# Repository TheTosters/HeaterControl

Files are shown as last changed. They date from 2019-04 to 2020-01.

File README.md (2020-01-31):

# IMPORTANT
Toolchain:
 * gcc-arm-none-eabi-8-2018-q4-major, or
 * gcc-arm-none-eabi-8-2019-q3-update-linux

NRF SDK:
 * nRF5_SDK_15.2.0_9412b96

You also need nrfprog tools and small patch for SDK from CMSIS. But this is handled by ```preapre_env.sh```

# To build & run tests...

This is super-glue solution, so your eyes will bleeed...
It will use host compiler (not cross-compiler) to build host based tests.
It is NOT ment to test all, only most complicated logic. So to have test build and run you have to:
```
cmake .. -DBUILD_TESTS=ON
make all
```

then you can call for example:
```./test/time_schedule_tests```

# Manual patching SDK
If you set C++ to use C++17 dialect then compilation fails :P You have to manualy patch NordicSDK (15.2) and upgrade CMSIS to have things working go here
[Arm CMSIS 5 on Github](https://github.com/ARM-software/CMSIS_5) and download following files which should be placed here:

| CMSIS file |  | Destination |
|------------| - |-------|
|libarm_cortexM4lf_math.a, libarm_cortexM4l_math.a  | > | nordic_SDK_15.2/components/toolchain/cmsis/dsp/GCC|
|arm_cortexM4lf_math.lib  arm_cortexM4l_math.lib | > | nordic_SDK_15.2/components/toolchain/cmsis/dsp/ARM
|CMSIS_5-develop/CMSIS/Core/Include | > |  nordic_SDK_15.2/components/toolchain/cmsis/include |

```clean & build```  all should work

# Variants
This repository contains several firmware variants. It can be used by setting proper defines for ```CMake```, most easy way to do it is to execute ```ccmake```. Below is list of build variants and their descriptions:

| Variant | Entry point | Description |
|-|-|-|
|Indoor SHT_ADV | main_indoor_1.cpp | BT: Advertisement <br> Sensor: SHT30 <br> Buttons: None <br> LED: None <br> Display: None |
|Indoor SHT_GATT | main_indoor_1a.cpp | BT: GATT <br> Sensor: SHT30 <br> Buttons: None <br> LED: None <br> Display: None |
|Indoor DS_FULL | main_indoor_1.cpp | BT: Advertisement <br> Sensor: DS18B20 <br> Buttons: yes <br> LED: None <br> Display: Yes |

# Origins
first instruction taken from:
https://github.com/Polidea/cmake-nRF5x
It is constantly changed and improved (or downproved :P)

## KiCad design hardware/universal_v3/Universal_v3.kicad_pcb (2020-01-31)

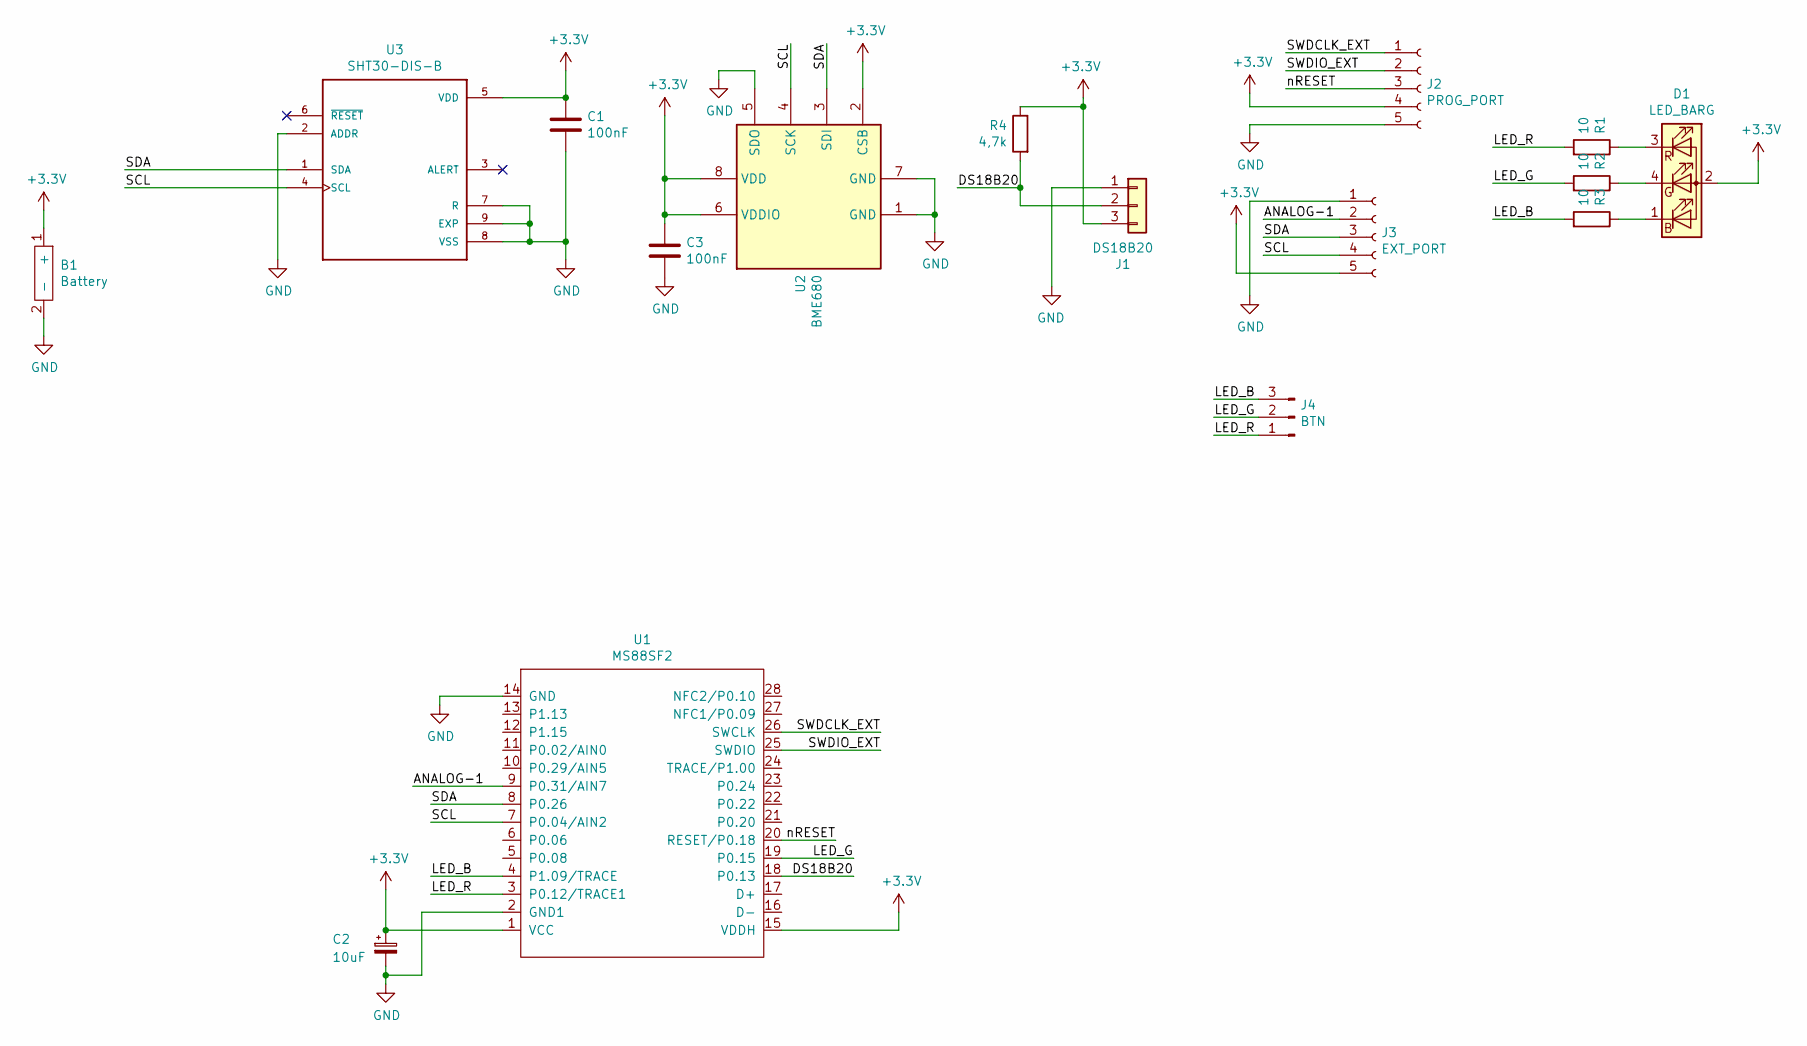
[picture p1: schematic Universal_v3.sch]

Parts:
B1: Battery; Cr2032-Holder
C1, C3: 100nF; C_0402_1005Metric
C2: 10uF; CP_EIA-2012-12_Kemet-R
D1: LED_BARG; Everlight_19-237_R6GHBHC-M07_2T
J1: DS18B20; 3Pads
J2: PROG_PORT; 5xPad
J3: EXT_PORT; 5xPad
J4: BTN; PinHeader_1x03_P2.54mm_Vertical
R1, R2, R3: 10; R_0402_1005Metric
R4: 4,7k; R_0402_1005Metric
U1: MS88SF2
U2: BME680; Bosch_LGA-8_3x3mm_P0.8mm_ClockwisePinNumbering
U3: SHT30-DIS-B; DFN250X250X100-9N

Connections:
+3V3: B1.1 (+), C1.1, C2.1, C3.1, D1.2 (A), J1.3, J2.4, J3.5, R4.1, U1.1 (VCC), U1.15 (VDDH), U2.2 (CSB), U2.6 (VDDIO), U2.8 (VDD), U3.5 (VDD)
/ANALOG-1: J3.2, U1.9 (P0.31/AIN7)
/DS18B20: J1.2, R4.2, U1.18 (P0.13)
/LED_B: J4.3, R3.2, U1.4 (P1.09/TRACE)
/LED_G: J4.2, R2.2, U1.19 (P0.15)
/LED_R: J4.1, R1.2, U1.3 (P0.12/TRACE1)
/SCL: J3.4, U1.7 (P0.04/AIN2), U2.4 (SCK), U3.4 (SCL)
/SDA: J3.3, U1.8 (P0.26), U2.3 (SDI), U3.1 (SDA)
/SWDCLK_EXT: J2.1, U1.26 (SWCLK)
/SWDIO_EXT: J2.2, U1.25 (SWDIO)
/nRESET: J2.3, U1.20 (RESET/P0.18)
GND: B1.2 (-), C1.2, C2.2, C3.2, J1.1, J2.5, J3.1, U1.2 (GND1), U1.14 (GND), U2.1 (GND), U2.5 (SDO), U2.7 (GND), U3.2 (ADDR), U3.7 (R), U3.8 (VSS), U3.9 (EXP)
unnamed: D1.1 (BK), R3.1
unnamed: D1.3 (RK), R1.1
unnamed: D1.4 (GK), R2.1

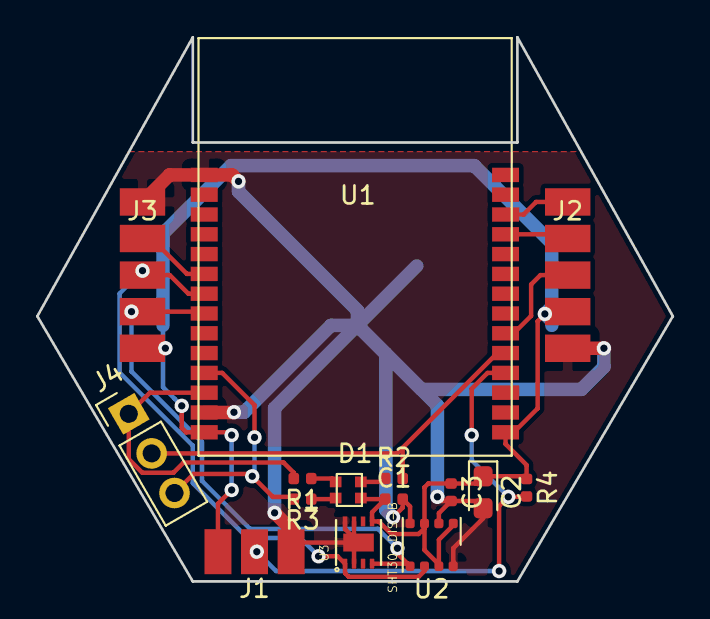
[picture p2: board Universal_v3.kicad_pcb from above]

Board: 2 copper layers, 35.3 x 30.2 mm, 16 parts (1 on the bottom side), 15 nets.

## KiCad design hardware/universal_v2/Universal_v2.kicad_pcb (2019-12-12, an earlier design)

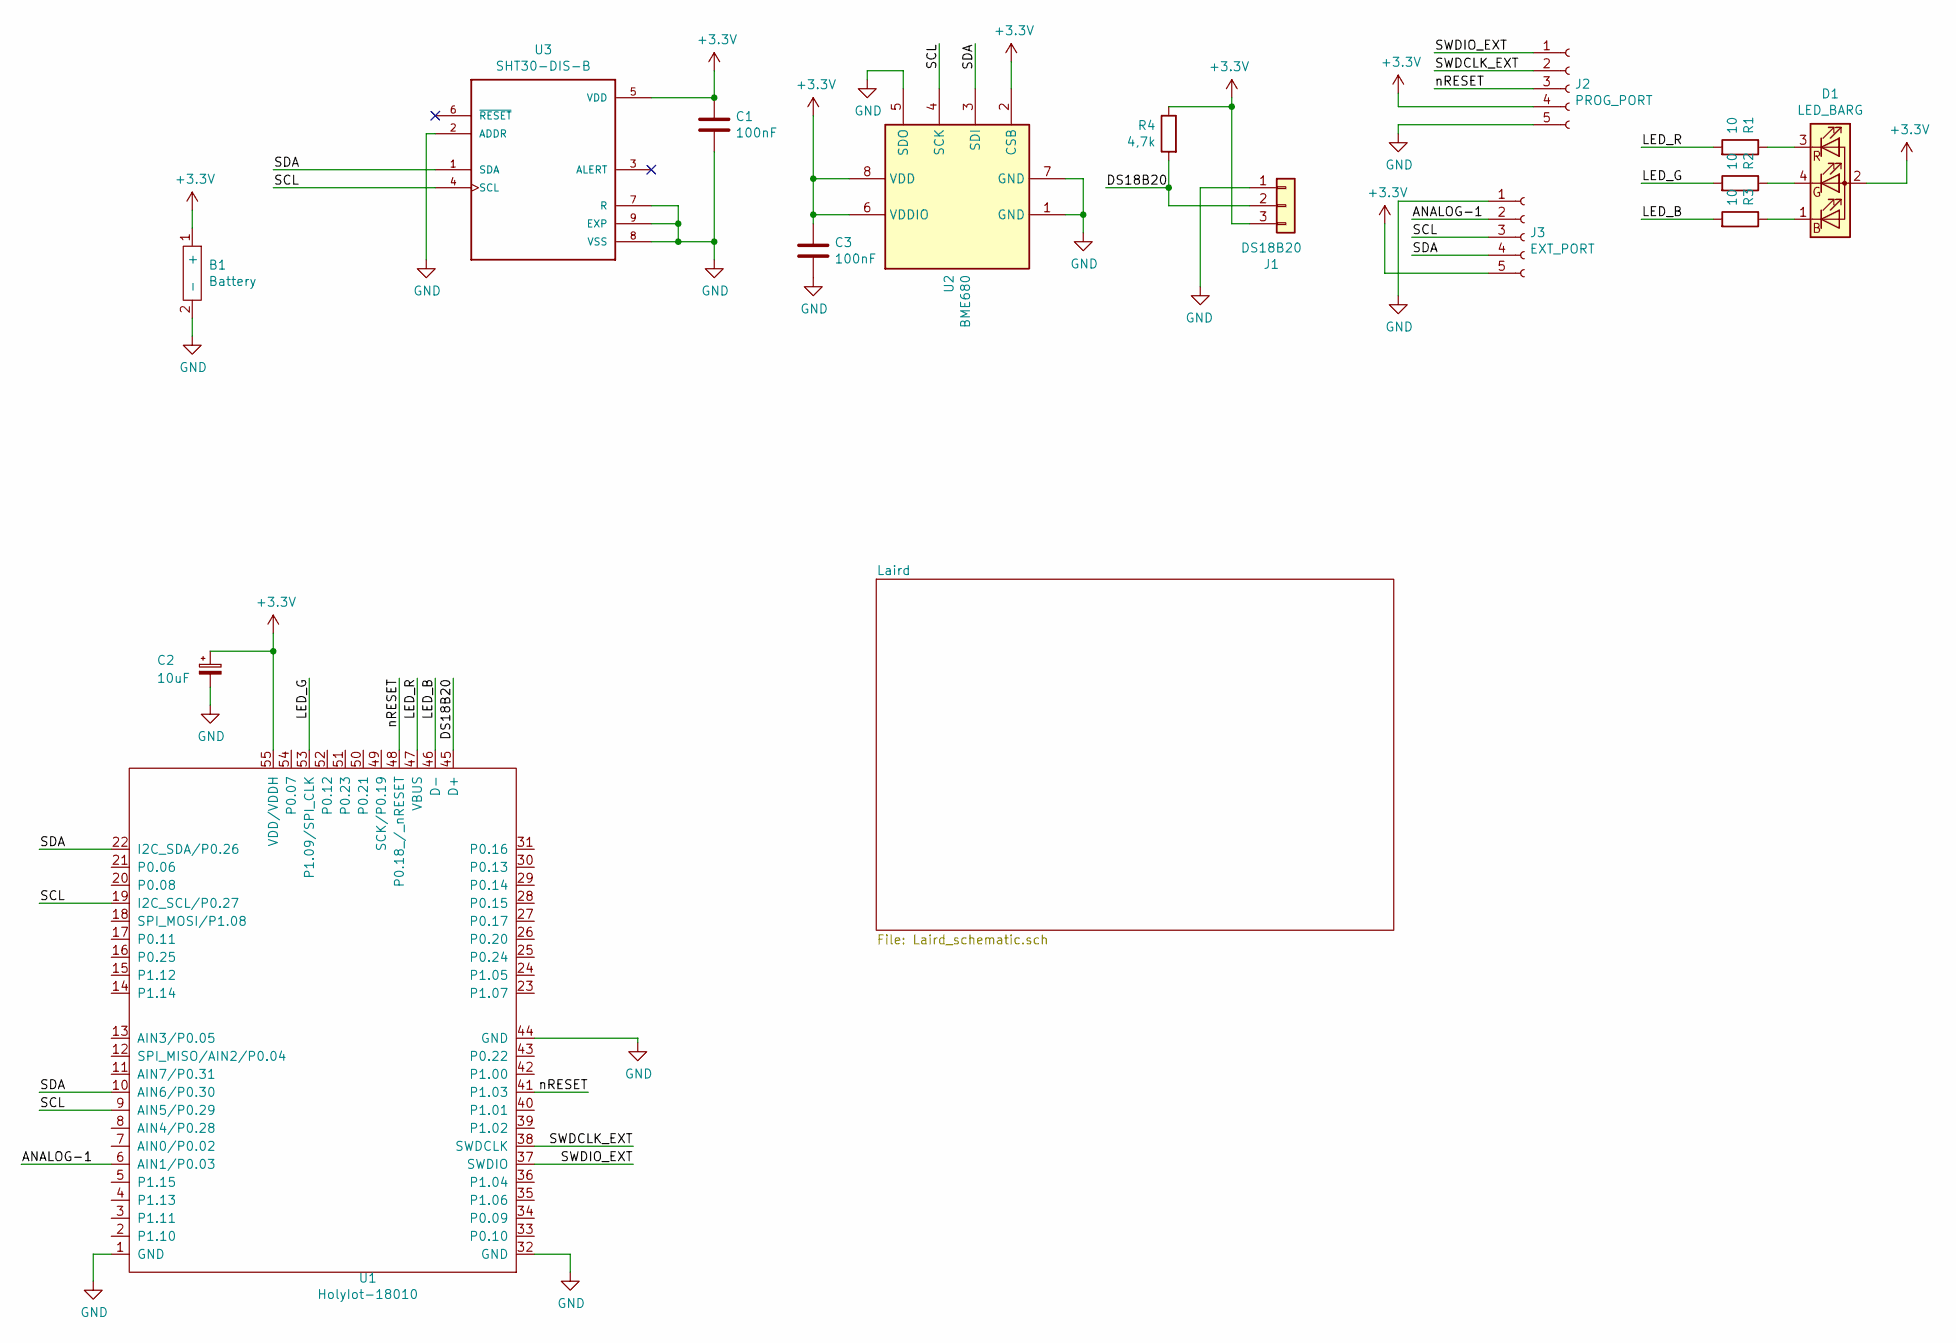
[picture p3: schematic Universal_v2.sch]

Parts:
B1: Battery; Cr2032-Holder
C1, C3: 100nF; C_0402_1005Metric
C2: 10uF; CP_EIA-2012-12_Kemet-R
D1: LED_BARG; Everlight_19-237_R6GHBHC-M07_2T
J1: DS18B20; 3Pads
J2: PROG_PORT; 5xPad
J3: EXT_PORT; 5xPad
R1, R2, R3: 10; R_0402_1005Metric
R4: 4,7k; R_0402_1005Metric
U1: HolyIot-18010; HolyIot_18010
U2: BME680; Bosch_LGA-8_3x3mm_P0.8mm_ClockwisePinNumbering
U3: SHT30-DIS-B; DFN250X250X100-9N

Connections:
+3V3: B1.1 (+), C1.1, C2.1, C3.1, D1.2 (A), J1.3, J2.4, J3.5, R4.1, U1.55 (VDD/VDDH), U2.2 (CSB), U2.6 (VDDIO), U2.8 (VDD), U3.5 (VDD); also elsewhere on the board
/ANALOG-1: J3.2, U1.6 (AIN1/P0.03)
/DS18B20: J1.2, R4.2, U1.45 (D+)
/LED_B: R3.2, U1.46 (D-)
/LED_G: R2.2, U1.53 (P1.09/SPI_CLK)
/LED_R: R1.2, U1.47 (VBUS)
/SCL: J3.3, U1.9 (AIN5/P0.29), U1.19 (I2C_SCL/P0.27), U2.4 (SCK), U3.4 (SCL)
/SDA: J3.4, U1.10 (AIN6/P0.30), U1.22 (I2C_SDA/P0.26), U2.3 (SDI), U3.1 (SDA)
/SWDCLK_EXT: J2.2, U1.38 (SWDCLK)
/SWDIO_EXT: J2.1, U1.37 (SWDIO)
/nRESET: J2.3, U1.41 (P1.03), U1.48 (P0.18_/_nRESET)
GND: B1.2 (-), C1.2, C2.2, C3.2, J1.1, J2.5, J3.1, U1.1 (GND), U1.32 (GND), U1.44 (GND), U2.1 (GND), U2.5 (SDO), U2.7 (GND), U3.2 (ADDR), U3.7 (R), U3.8 (VSS), U3.9 (EXP); also elsewhere on the board
unnamed: D1.1 (BK), R3.1
unnamed: D1.3 (RK), R1.1
unnamed: D1.4 (GK), R2.1

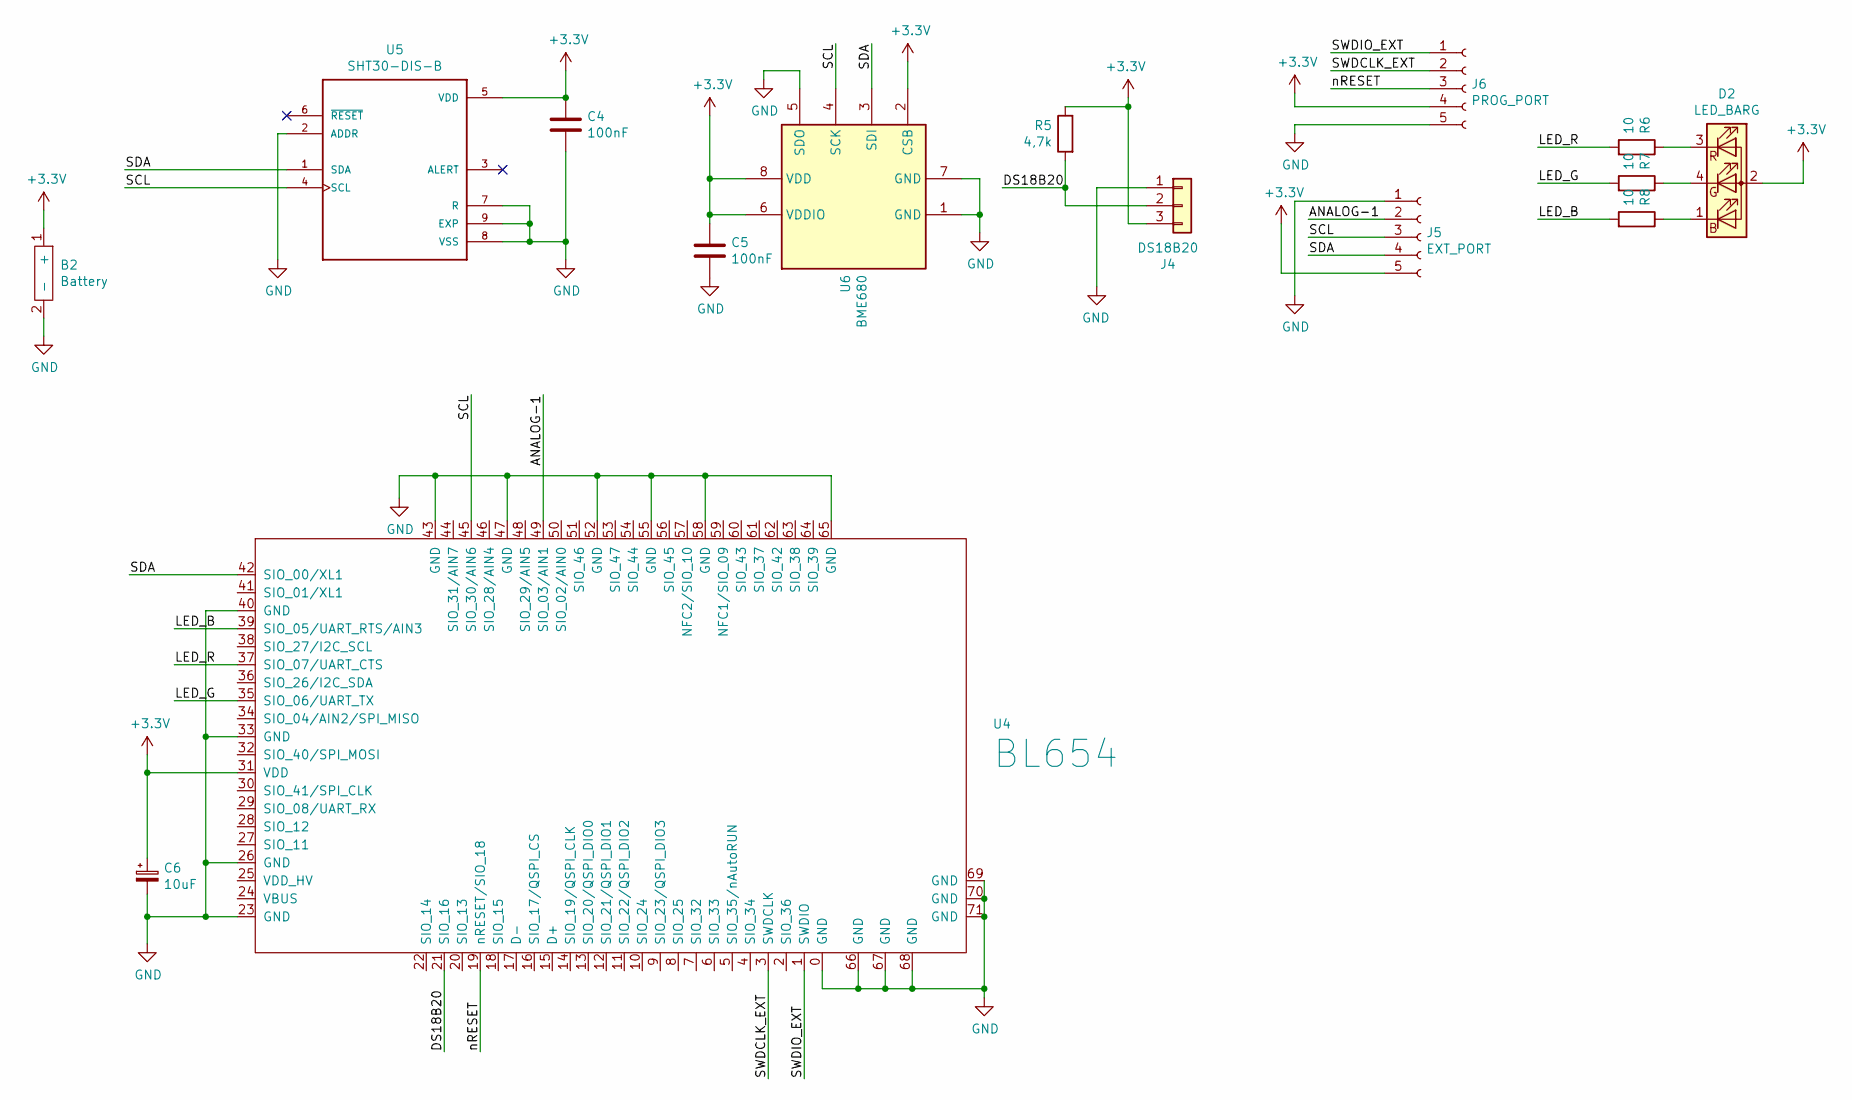
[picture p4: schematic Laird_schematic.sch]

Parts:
B2: Battery; Cr2032-Holder
C4, C5: 100nF; C_0402_1005Metric
C6: 10uF; CP_EIA-2012-12_Kemet-R
D2: LED_BARG; Everlight_19-237_R6GHBHC-M07_2T
J4: DS18B20; 3Pads
J5: EXT_PORT; 5xPad
J6: PROG_PORT; 5xPad
R5: 4,7k; R_0402_1005Metric
R6, R7, R8: 10; R_0402_1005Metric
U4: BL654
U5: SHT30-DIS-B; DFN250X250X100-9N
U6: BME680; Bosch_LGA-8_3x3mm_P0.8mm_ClockwisePinNumbering

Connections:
+3V3: B2.1 (+), C4.1, C5.1, C6.1, D2.2 (A), J4.3, J5.5, J6.4, R5.1, U4.31 (VDD), U5.5 (VDD), U6.2 (CSB), U6.6 (VDDIO), U6.8 (VDD); also elsewhere on the board
/Laird/ANALOG-1: J5.2, U4.49 (SIO_03/AIN1)
/Laird/DS18B20: J4.2, R5.2, U4.21 (SIO_16)
/Laird/LED_B: R8.2, U4.39 (SIO_05/UART_RTS/AIN3)
/Laird/LED_G: R7.2, U4.35 (SIO_06/UART_TX)
/Laird/LED_R: R6.2, U4.37 (SIO_07/UART_CTS)
/Laird/SCL: J5.3, U4.45 (SIO_30/AIN6), U5.4 (SCL), U6.4 (SCK)
/Laird/SDA: J5.4, U4.42 (SIO_00/XL1), U5.1 (SDA), U6.3 (SDI)
/Laird/SWDCLK_EXT: J6.2, U4.3 (SWDCLK)
/Laird/SWDIO_EXT: J6.1, U4.1 (SWDIO)
/Laird/nRESET: J6.3, U4.19 (nRESET/SIO_18)
GND: B2.2 (-), C4.2, C5.2, C6.2, J4.1, J5.1, J6.5, U4.0 (GND), U4.23 (GND), U4.26 (GND), U4.33 (GND), U4.40 (GND), U4.43 (GND), U4.47 (GND), U4.52 (GND), U4.55 (GND), U4.58 (GND), U4.65 (GND), U4.66 (GND), U4.67 (GND), U4.68 (GND), U4.69 (GND), U4.70 (GND), U4.71 (GND), U5.2 (ADDR), U5.7 (R), U5.8 (VSS), U5.9 (EXP), U6.1 (GND), U6.5 (SDO), U6.7 (GND); also elsewhere on the board
unnamed: D2.1 (BK), R8.1
unnamed: D2.3 (RK), R6.1
unnamed: D2.4 (GK), R7.1

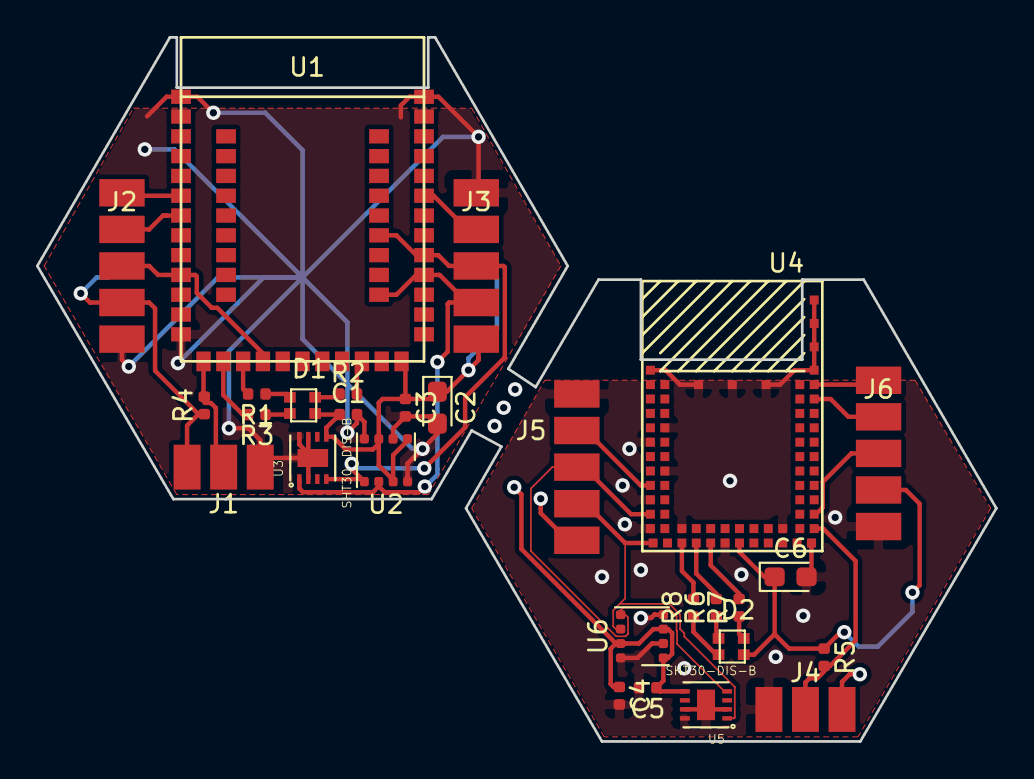
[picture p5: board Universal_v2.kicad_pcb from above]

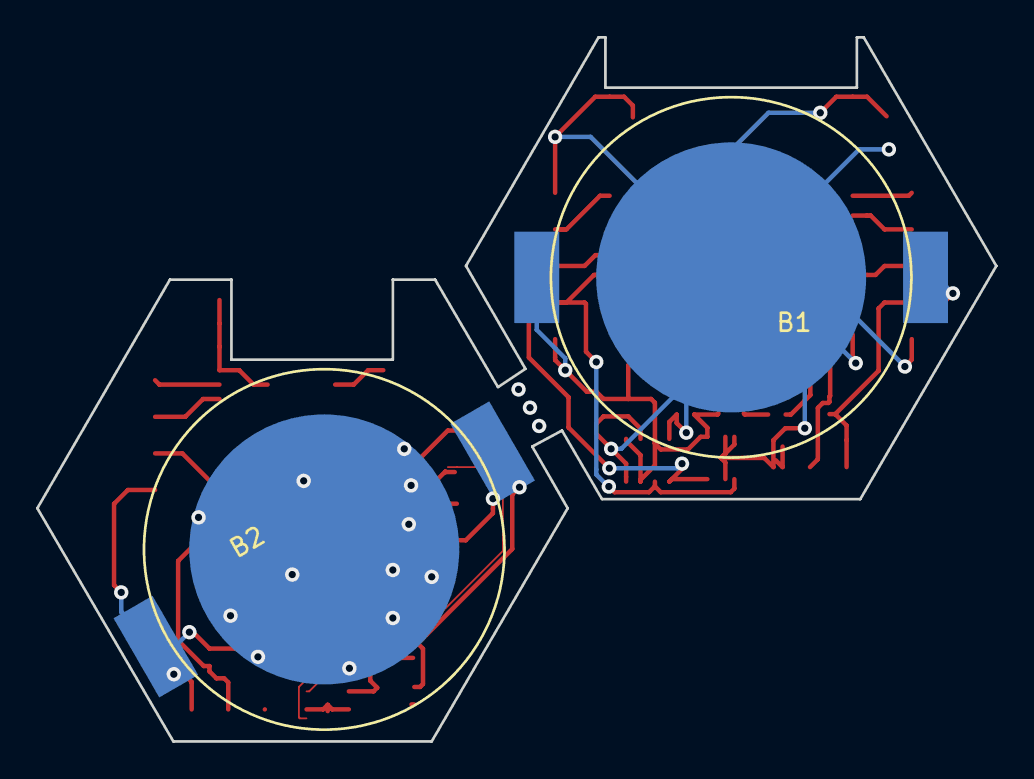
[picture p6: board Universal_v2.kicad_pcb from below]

Board: 2 copper layers, 53.3 x 39.1 mm, 30 parts (2 on the bottom side), 28 nets.

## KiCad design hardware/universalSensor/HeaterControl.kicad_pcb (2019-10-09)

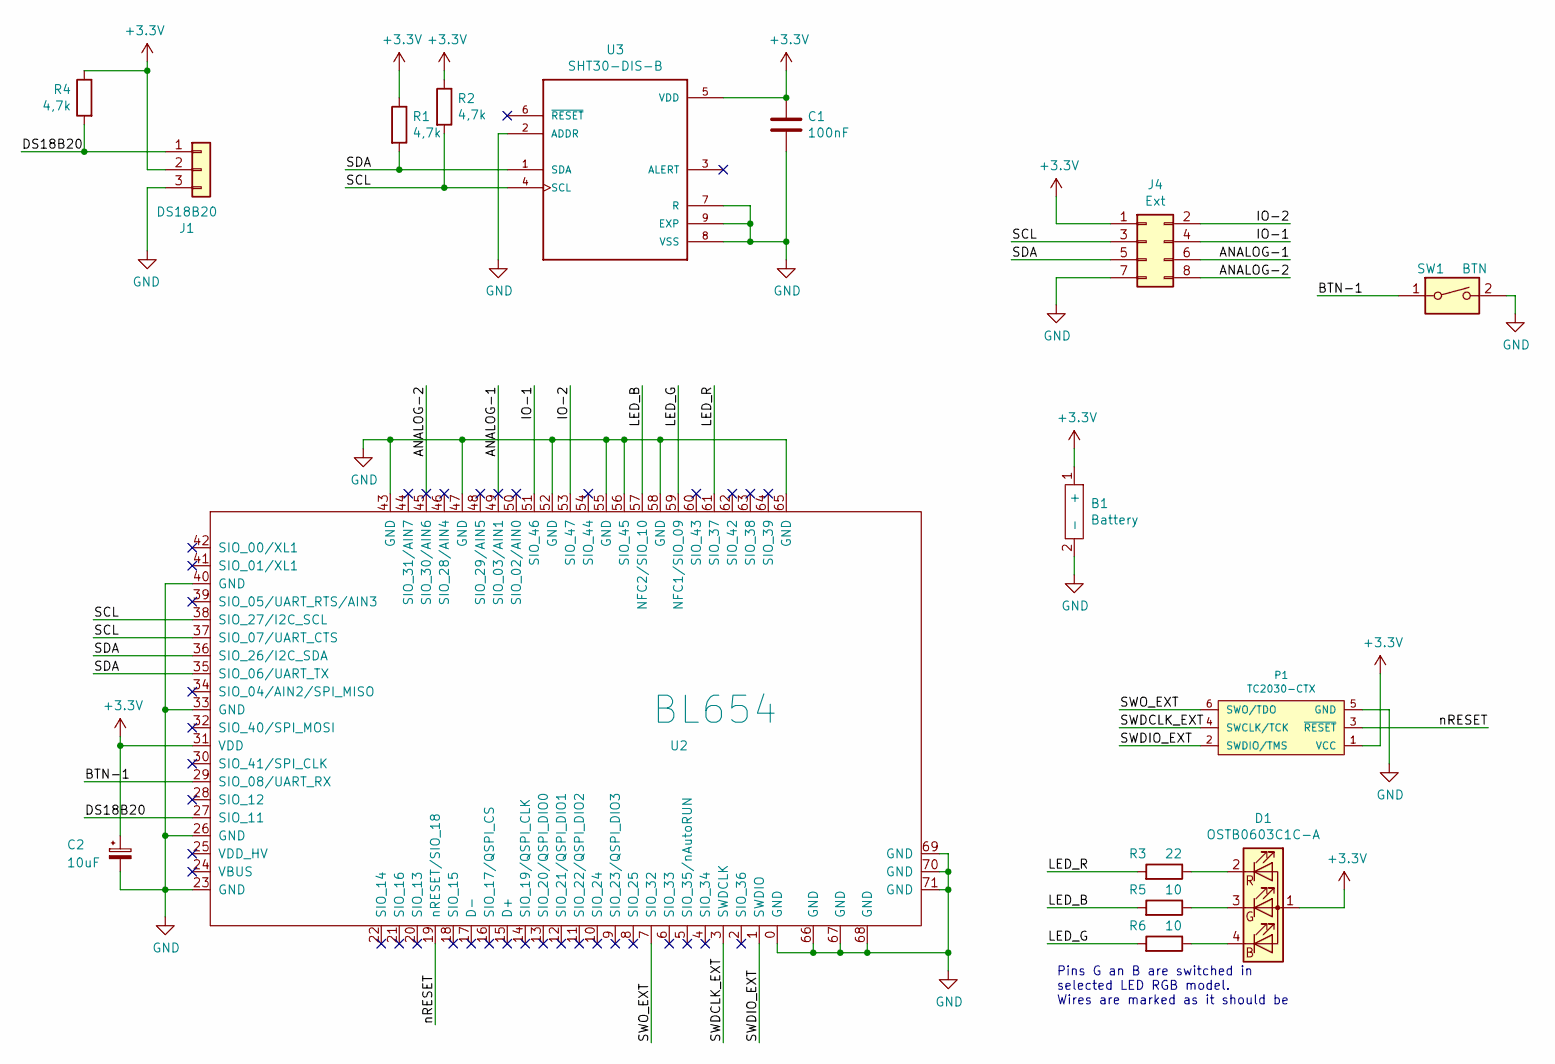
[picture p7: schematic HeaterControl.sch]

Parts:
B1: Battery; Cr2032-Holder
C1: 100nF; C_0402_1005Metric
C2: 10uF; CP_EIA-2012-12_Kemet-R
D1: OSTB0603C1C-A; LED_PACKAGE_1.6x1.5mm
J1: DS18B20; PinHeader_1x03_P2.54mm_Vertical_SMD_Pin1Left
J4: Ext; PinHeader_2x04_P1.00mm_Vertical_SMD
P1: TC2030-CTX; TC2030-NL_SMALL
R1, R2, R4: 4,7k; R_0402_1005Metric
R3: 22; R_0402_1005Metric
R5, R6: 10; R_0402_1005Metric
SW1: BTN; R_1206_3216Metric
U2: BL654
U3: SHT30-DIS-B; DFN250X250X100-9N

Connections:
+3V3: B1.1 (+), C1.1, C2.1, D1.1 (A), J1.2, J4.1, P1.1 (VCC), R1.1, R2.1, R4.1, U2.31 (VDD), U3.5 (VDD); also elsewhere on the board
/ANALOG-1: J4.6, U2.49 (SIO_03/AIN1)
/ANALOG-2: J4.8, U2.45 (SIO_30/AIN6)
/BTN-1: SW1.1, U2.29 (SIO_08/UART_RX)
/DS18B20: J1.1, R4.2, U2.27 (SIO_11)
/IO-1: J4.4, U2.51 (SIO_46)
/IO-2: J4.2, U2.53 (SIO_47)
/LED_B: R5.2, U2.57 (NFC2/SIO_10)
/LED_G: R6.2, U2.59 (NFC1/SIO_09)
/LED_R: R3.2, U2.61 (SIO_37)
/SCL: J4.3, R2.2, U2.37 (SIO_07/UART_CTS), U2.38 (SIO_27/I2C_SCL), U3.4 (SCL)
/SDA: J4.5, R1.2, U2.35 (SIO_06/UART_TX), U2.36 (SIO_26/I2C_SDA), U3.1 (SDA)
/SWDCLK_EXT: P1.4 (SWCLK/TCK), U2.3 (SWDCLK); also elsewhere on the board
/SWDIO_EXT: P1.2 (SWDIO/TMS), U2.1 (SWDIO); also elsewhere on the board
/SWO_EXT: P1.6 (SWO/TDO), U2.7 (SIO_32); also elsewhere on the board
/nRESET: P1.3 (~RESET~), U2.19 (nRESET/SIO_18); also elsewhere on the board
GND: B1.2 (-), C1.2, C2.2, J1.3, J4.7, P1.5 (GND), SW1.2, U2.0 (GND), U2.23 (GND), U2.26 (GND), U2.33 (GND), U2.40 (GND), U2.43 (GND), U2.47 (GND), U2.52 (GND), U2.55 (GND), U2.56 (SIO_45), U2.58 (GND), U2.65 (GND), U2.66 (GND), U2.67 (GND), U2.68 (GND), U2.69 (GND), U2.70 (GND), U2.71 (GND), U3.2 (ADDR), U3.7 (R), U3.8 (VSS), U3.9 (EXP); also elsewhere on the board
unnamed: D1.2 (RK), R3.1
unnamed: D1.3 (GK), R5.1
unnamed: D1.4 (BK), R6.1

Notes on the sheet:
Pins G an B are switched in selected LED RGB model. Wires are marked as it should be

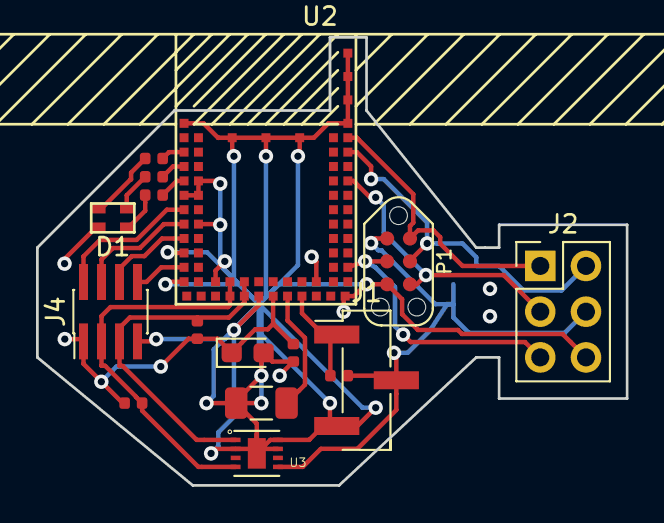
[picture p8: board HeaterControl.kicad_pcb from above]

Board: 2 copper layers, 32.8 x 24.9 mm, 17 parts (1 on the bottom side), 20 nets.

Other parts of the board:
J2: DEV_PORT; PinHeader_2x03_P2.54mm_Vertical

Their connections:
+3V3: J2.4; also elsewhere on the board
/SWDCLK_EXT: J2.2; also elsewhere on the board
/SWDIO_EXT: J2.1; also elsewhere on the board
/SWO_EXT: J2.3; also elsewhere on the board
/nRESET: J2.5; also elsewhere on the board
GND: J2.6; also elsewhere on the board

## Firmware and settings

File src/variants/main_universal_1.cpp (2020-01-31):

extern "C" {
#include <components/libraries/delay/nrf_delay.h>
#include <components/boards/boards.h>
#include <components/libraries/log/nrf_log_ctrl.h>
#include <components/libraries/log/nrf_log.h>
#include <components/libraries/log/nrf_log_default_backends.h>
#include <components/libraries/util/app_error.h>
#include <components/softdevice/common/nrf_sdh.h>
#include <components/softdevice/common/nrf_sdh_ble.h>
#include <components/libraries/pwr_mgmt/nrf_pwr_mgmt.h>
#include <components/libraries/bsp/bsp.h>
#include <components/libraries/timer/app_timer.h>
#include <components/ble/ble_services/ble_dfu/ble_dfu.h>
#include <integration/nrfx/legacy/nrf_drv_clock.h>
#include <config/nrf52840/config/sdk_config.h>
}

#include "bridges/i2c_bridge.h"
#include "buttons.h"
#include "display.h"
#include "sensors/sensor_factory.h"
//#include "bluetooth/btle_transmiter.h"
#include "calendar.h"
#include "resources/xbm_icons.h"
#include "screens/default_screen.h"
#include "screens/status_screen.h"
#include "screens/time_setup_screen.h"
#include "screens/screens_stack.h"
#include "observable.h"
#include "events_dispatcher.h"
#include "schedule/temperatureScheduler.h"
#include "schedule/weekScheduleBuilder.h"
#include "heating_model.h"
#include "types/hardware_pin.h"
#include "leds/led_factory.h"
#include "leds/led_color.h"
//#include "bluetooth/gatt_stack.h"
//#include "bluetooth/services/gatt_service.h"
#include "communication.h"
#include <stdint.h>

#define APP_BLE_OBSERVER_PRIO           3
#define APP_BLE_CONN_CFG_TAG            1

extern void setupScreens();

void powerManagementInit() {
  ret_code_t err_code;
  err_code = nrf_pwr_mgmt_init();
  APP_ERROR_CHECK(err_code);
}

void initLowFreqClock() {
  ret_code_t err_code = nrf_drv_clock_init();
  APP_ERROR_CHECK(err_code);
  nrf_drv_clock_lfclk_request(NULL);
}

uint32_t millis(void)
{
  return(app_timer_cnt_get() / 32.768);
}
#define OVERFLOW_1 ((uint32_t)(0xFFFFFFFF/32.768))

uint32_t compareMillis(uint32_t previousMillis, uint32_t currentMillis)
{
  if(currentMillis < previousMillis) {
    return currentMillis + OVERFLOW_1 + 1 - previousMillis;
  } else {
    return currentMillis - previousMillis;
  }
}

void setupMeasureOnButton() {
#if defined(MEASURE_ON_BUTTON_PRESS) && MEASURE_ON_BUTTON_PRESS == 1
  buttons().addObserver([](ButtonId event) {
    RGBLeds().setColor(LedColor::GREEN, 1 * 1000);
    Communication::sendMeasurementsNow();
  });
  NRF_LOG_INFO("ENABLE: Measure on Button press");
#else
  NRF_LOG_INFO("DISABLE: Measure on Button press");
#endif
}

void pinsFix() {
  //in this hardware following pins are bridged and need to be set as a high impedance
  //P0.27 & P0.7
  //P0.26 & P0.6
  nrf_gpio_cfg_input(NRF_GPIO_PIN_MAP(0, 6), NRF_GPIO_PIN_NOPULL);
  nrf_gpio_cfg_input(NRF_GPIO_PIN_MAP(0, 7), NRF_GPIO_PIN_NOPULL);
  NRF_LOG_INFO("ENABLE: Pins P0.06 & P0.07 as high impedance");
}

int main( int argc, const char* argv[] ) {
  NRF_LOG_INIT(NULL);
  NRF_LOG_DEFAULT_BACKENDS_INIT();
  NRF_LOG_INFO("Start");
  NRF_LOG_FLUSH();

  bsp_board_init(BSP_INIT_LEDS | BSP_INIT_BUTTONS);
  pinsFix();
  powerManagementInit();
  initLowFreqClock();

  ret_code_t err = app_timer_init();
  APP_ERROR_CHECK(err);

  RGBLeds().setColor(LedColor::NONE, 3*1000);

  //All data types which are used by classes which uses dispatching into main
  //thread should be placed here!
  EventsDispatcher<10,
    ButtonId, app_timer_event_t, BtleTransmiter*, BleEventPtr> dispatcher;

  Communication::build();
  Communication::start();
  NRF_LOG_FLUSH();

  setupScreens();
  setupMeasureOnButton();

#ifdef DEBUG_BUILD
  sensors().addObserver([](TemperatureC t, RelativeHumidity h, BatteryPrc  b){
    NRF_LOG_WARNING("Temp: %s; Hum: %s, Batt: %s\n",
        t.toString().c_str(), h.toString().c_str(), b.toString().c_str() );
  });
  NRF_LOG_INFO("ENABLE: Debug sensors dump");
#endif

  NRF_LOG_INFO("Config done, entering main loop");
  NRF_LOG_FLUSH();

  RGBLeds().setColor(LedColor::GREEN, 3 * 1000);
  while (true) {
    dispatcher.process();
    nrf_pwr_mgmt_run();
  }
  return 0;
}

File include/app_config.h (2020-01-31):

//This are defines for sdk

//Bluetooth magic
#define PEER_MANAGER_ENABLED 1
#define NRF_BLE_QWR_ENABLED 1
#define FDS_ENABLED 1
#define NRF_BLE_GATT_ENABLED 1
#define BLE_ADVERTISING_ENABLED 1
#define NRF_BLE_CONN_PARAMS_ENABLED 1
#define NRF_SDH_BLE_PERIPHERAL_LINK_COUNT 1
#define NRF_BLE_CONN_PARAMS_MAX_SLAVE_LATENCY_DEVIATION 499
#define NRF_BLE_CONN_PARAMS_MAX_SUPERVISION_TIMEOUT_DEVIATION 65535
#define NRF_FSTORAGE_ENABLED 1
#define NRF_FSTORAGE_PARAM_CHECK_DISABLED 0
//+1 because of DFU
#define NRF_SDH_BLE_VS_UUID_COUNT (5+0)
#define NRF_SDH_BLE_LOG_LEVEL 4
#define NRF_SDH_LOG_LEVEL 4
#define NRF_SDH_SOC_LOG_LEVEL 4

/* Needed in production board, wasn't needed in dev board*/
#define NRF_SDH_CLOCK_LF_RC_CTIV 16
#define NRF_SDH_CLOCK_LF_RC_TEMP_CTIV 2
#define NRF_SDH_CLOCK_LF_ACCURACY NRF_CLOCK_LF_ACCURACY_500_PPM
#define NRF_SDH_CLOCK_LF_SRC 0
/* ^------- */

//SAADC
#define SAADC_ENABLED 1
#define SAADC_CONFIG_RESOLUTION 1
#define SAADC_CONFIG_OVERSAMPLE 0
#define SAADC_CONFIG_LP_MODE 0
#define SAADC_CONFIG_IRQ_PRIORITY 6

#define NRFX_SAADC_ENABLED 1
#define NRFX_SAADC_CONFIG_RESOLUTION 1
#define NRFX_SAADC_CONFIG_OVERSAMPLE 0
#define NRFX_SAADC_CONFIG_LP_MODE 0
#define NRFX_SAADC_CONFIG_IRQ_PRIORITY 6

#define GPIO_COUNT 2
//BSP support
#define BUTTON_ENABLED 1
#define APP_GPIOTE_ENABLED 1
#define NRFX_GPIOTE_ENABLED 1
#define GPIOTE_ENABLED 1
#define GPIOTE_CONFIG_NUM_OF_LOW_POWER_EVENTS 4

#define APP_FIFO_ENABLED 1
#define APP_SCHEDULER_ENABLED 1

//Timer support
#define APP_TIMER_ENABLED 1
#define APP_TIMER_CONFIG_USE_SCHEDULER 1  //we want timer to use app scheduler
#define NRF_CLOCK_ENABLED 1
#define CLOCK_CONFIG_LF_SRC 1

//Logs
#ifdef DEBUG_BUILD
#define NRF_LOG_ENABLED 1
#define NRF_LOG_USES_TIMESTAMP 0
#define NRF_LOG_BACKEND_UART_ENABLED 0
#define NRF_LOG_BACKEND_RTT_ENABLED 1
#define NRF_LOG_DEFERRED 0
#define NRF_LOG_DEFAULT_LEVEL 4
#else
#define NRF_LOG_ENABLED 0
#define NRF_LOG_USES_TIMESTAMP 0
#define NRF_LOG_BACKEND_UART_ENABLED 0
#define NRF_LOG_BACKEND_RTT_ENABLED 0
#define NRF_LOG_DEFERRED 0
#define NRF_LOG_DEFAULT_LEVEL 4
#endif

//SEGGER RTT
#define NRF_LOG_BACKEND_RTT_TEMP_BUFFER_SIZE 64
#define NRF_LOG_BACKEND_RTT_TX_RETRY_CNT 5
#define NRF_LOG_BACKEND_RTT_TX_RETRY_DELAY_MS 2

#define SEGGER_RTT_CONFIG_BUFFER_SIZE_UP 512
#define SEGGER_RTT_CONFIG_MAX_NUM_UP_BUFFERS 2
#define SEGGER_RTT_CONFIG_BUFFER_SIZE_DOWN 16
#define SEGGER_RTT_CONFIG_MAX_NUM_DOWN_BUFFERS 2
#define SEGGER_RTT_CONFIG_DEFAULT_MODE 0

//SoftDevice
#define NRF_SDH_BLE_ENABLED 1
#define NRF_SDH_ENABLED 1
#define NRF_SDH_SOC_ENABLED 1
#define NRF_SDH_DISPATCH_MODEL NRF_SDH_DISPATCH_MODEL_APPSH

//Power management
#define NRF_PWR_MGMT_ENABLED 1

//App Scheduler
#define APP_SCHEDULER_ENABLED 1
#define APP_SCHEDULER_WITH_PAUSE 0
#define APP_SCHEDULER_WITH_PROFILER 0

//TWI
#define TWI_ENABLED 1
#define TWI0_ENABLED 1
#define TWI0_USE_EASY_DMA 1

//#define NRFX_TWIM_CONFIG_LOG_ENABLED 1
//#define TWI_CONFIG_LOG_ENABLED 1
//#define TWI_CONFIG_LOG_LEVEL 4



//DFU
//#define BL_SETTINGS_ACCESS_ONLY 1
//#define NRF_DFU_SVCI_ENABLED 1
//#define NRF_DFU_TRANSPORT_BLE 1
//#define BLE_DFU_ENABLED 1

//#define CRC16_ENABLED 1
//#define FDS_ENABLED 1
//#define NRF_FSTORAGE_ENABLED 1
//#define NRF_PWR_MGMT_CONFIG_FPU_SUPPORT_ENABLED 1
//#define NRF_PWR_MGMT_CONFIG_AUTO_SHUTDOWN_RETRY 1
////#define NRF_SDH_BLE_VS_UUID_COUNT 1
//#define NRF_SDH_BLE_SERVICE_CHANGED 1
//#define NRF_SDH_ENABLED 1
//#define NRF_SDH_SOC_ENABLED 1
//#define GPIOTE_ENABLED 1
//#define NRFX_GPIOTE_ENABLED 1
//#define GPIOTE_CONFIG_NUM_OF_LOW_POWER_EVENTS 4
//#define NRFX_CLOCK_ENABLED 1

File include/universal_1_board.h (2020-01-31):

#pragma once

//This is custom board done for this project, it refers to PCB: hardware/universalSensor

//This things need to be set from CMAKE or compiler options
#ifndef BOARD_SENSOR
  #error "BOARD_SENSOR macro need to be set!"
#endif

#ifndef BOARD_COMMUNICATION
  #error "BOARD_COMMUNICATION macro need to be set!"
#endif

#ifndef BOARD_RGB_LED
  #warning "BOARD_RGB_LED  macro should be set, falback to NONE"
  #define BOARD_RGB_LED   RGBLedType::NONE
#endif

#ifndef MEASURE_ON_BUTTON_PRESS
  #warning "MEASURE_ON_BUTTON_PRESS is not set by build system, falback to 0"
  #define MEASURE_ON_BUTTON_PRESS   1
#endif

#ifndef BUTTONS_NUMBER
  #warning "BUTTONS_NUMBER is not set by build system, falback to 1"
  #define BUTTONS_NUMBER  1
#endif

#ifndef LEDS_NUMBER
  #warning "LEDS_NUMBER is not set by build system, falback to 0"
  #define LEDS_NUMBER    0  //BSP LEDS not RGB!
#endif

#ifndef DISPLAY
  #warning "DISPLAY is not set by build system, falback to 0"
  #define DISPLAY        0
#endif


//I2C
#define CONFIG_SDA_PIN      NRF_GPIO_PIN_MAP(0, 26)
#define CONFIG_SCL_PIN      NRF_GPIO_PIN_MAP(0, 27)

//#define MEASURE_INTERVAL_MS   (5 * 60 * 1000)
#define MEASURE_INTERVAL_MS   (1 * 1000)
#define MEASURE_DELTA_TEMP    (0.5f)
#define MEASURE_DELTA_HUM     (5)

//BSP buttons
#define BUTTON_PREV     NRF_GPIO_PIN_MAP(0, 6)
#define BUTTON_PULL     NRF_GPIO_PIN_PULLUP
#define BUTTONS_ACTIVE_STATE 0
#define BUTTONS_LIST   {BUTTON_PREV}
#define BSP_BUTTON_0   BUTTON_PREV

//RGB led config (Not BSP led)
#define CONFIG_RGB_R_PIN      NRF_GPIO_PIN_MAP(1, 14)
#define CONFIG_RGB_G_PIN      NRF_GPIO_PIN_MAP(1, 15)
#define CONFIG_RGB_B_PIN      NRF_GPIO_PIN_MAP(1, 5)

//unused but helps to compile ;)
#define CONFIG_SSD1306_I2C_ADDRESS   ((uint8_t)0x3C)
#define CONFIG_DS18B20_PIN           NRF_GPIO_PIN_MAP(0, 1)
#define BUTTONS_ACTIVE_STATE         0
#define LEDS_ACTIVE_STATE            0

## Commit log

2019-03-24 First version of hardware
    [HeaterControl.kicad_pcb, HeaterControl.sch]
2019-03-28 Fix draw library, add ds18b20 measurements
    [main.cpp]
2019-03-29 add custom boards, improved build system
2019-03-29 Buttons stub now works
2019-04-01 Fix build scripts, add display abstraction
    [app_config.h, dev_board.h, main.cpp]
2019-04-03 Add base for classes which uses timer
2019-04-09 used tempC type in sensors
2019-04-10 - moved unit to separete class - typenapes changed to upper case - fixed temperature comparision in sensors
2019-04-11 Add main thread dispatcher
2019-04-11 - generalization of sensors usage
2019-04-11 moved timing const to specific sensors
2019-04-11 sensors factory and unification with other parts of code
2019-04-11 cleanup + fix for merge
    [main.cpp]
2019-04-11 Trait based factory for sensors
2019-04-12 removed power on/off on hardware sensors/oled
2019-04-12 Reworked display power management and screen stack rendering
    [main.cpp]
2019-04-12 Reworked power management cycle on sensors
    [ds18b20.h, main.cpp]
2019-04-12 Reworked observer subsystem. Add status screen
    [ds18b20.h, main.cpp]
2019-04-13 Removed Sensor/Oled PWR circuts
    [HeaterControl.kicad_pcb, HeaterControl.sch]
2019-04-13 Labels on PCB rearanged
    [HeaterControl.kicad_pcb]
2019-04-13 Add another schematic, add capacitor and rework 3v3 on laird
    [HeaterControl.kicad_pcb, HeaterControl.sch, Reciever.kicad_pcb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]
2019-04-16 - calendar modified - added weekUnit - partiatly done temperatureSheduler
2019-04-16 Start work of integration heating plan
2019-04-16 Add heating model, still under work
2019-04-17 PCB layout fo reciever
    [Reciever.sch]
2019-04-17 - add all functionalities to temperatureSheduler
2019-05-05 Next stages of BTLE charact. implementation
2019-05-06 Refactors, bug fixing, still not stable
    [app_config.h]
2019-05-07 Sensor values are propageted to GATT, notification still not working
    [main.cpp]
2019-05-08 cleanup, temp stability fix (disabled flash), reenabling advert
    [app_config.h, main.cpp]
2019-05-10 changes in characteristic type hierarchy, linked GATT to Sensors
2019-06-19 Add prod dev required defines, add battery level
2019-09-10 New universal sensor board
    [HeaterControl.kicad_pcb, HeaterControl.sch]
2019-10-07 Add RGB Led support, and universal board definition
2019-10-09 Add dev port do univeral board
    [HeaterControl.kicad_pcb]
2019-10-09 Add Green diode indication on measure on demand
2019-10-13 RGB led emulation class
2019-11-03 Universal board v2
    [Universal_v2.kicad_pcb, Universal_v2.sch]
2019-11-06 Another version of hardware concept
    [Universal_v2.kicad_pcb]
2019-12-11 Hardware v2, upgrade
    [Universal_v2.kicad_pcb, Universal_v2.sch]
2019-12-12 Final hardware version 2
    [Laird_schematic.sch, Universal_v2.kicad_pcb, Universal_v2.sch]
2019-12-12 Fixed mechanical shape
    [Universal_v2.kicad_pcb]
2019-12-28 RGB leds now compiles for NONE variant
2020-01-31 Hardveare Universal_v3 created
    [Universal_v3.kicad_pcb, Universal_v3.sch]
